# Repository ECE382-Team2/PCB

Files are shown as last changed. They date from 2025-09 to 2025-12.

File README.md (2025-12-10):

# OreoFT PCB

We used the Capacitance Comb library to automatically generate various configurations of capacitive comb structures for our capacitive force-torque (FT) sensor. Using the library in double-sided mode allowed us to create identical electrode traces for the top and bottom layers, ensuring symmetry and consistency. This automated generation process streamlined our sensor bring-up and improved design repeatability across different PCB configurations.

## PCB Configurations
There are multiple PCB configurations that vary by trace width, trace spacing, and the overall diameter of the electrode array (the circle formed by the four quadrants of electrodes).

### Electrode Array Diameter: 35 mm

| Option | Trace Width (mm) | Trace Spacing (mm) |
|:---:|:---:|:---:|
| 1 | 0.2 | 0.2 |
| 2 | 0.4 | 0.4 |
| 3 | 0.4 | 0.2 |

### Electrode Array Diameter: 52 mm

| Option | Trace Width (mm) | Trace Spacing (mm) |
|:---:|:---:|:---:|
| 1 | 0.7 | 0.2 |
| 2 | 1.0 | 0.2 |
| 3 | 0.7 | 0.1 |

These configurations allow us to test how trace geometry and sensor diameter affect the sensor's response and sensitivity. 
Different trace configurations can be generated using the Capacitance Comb library parameters accordingly.

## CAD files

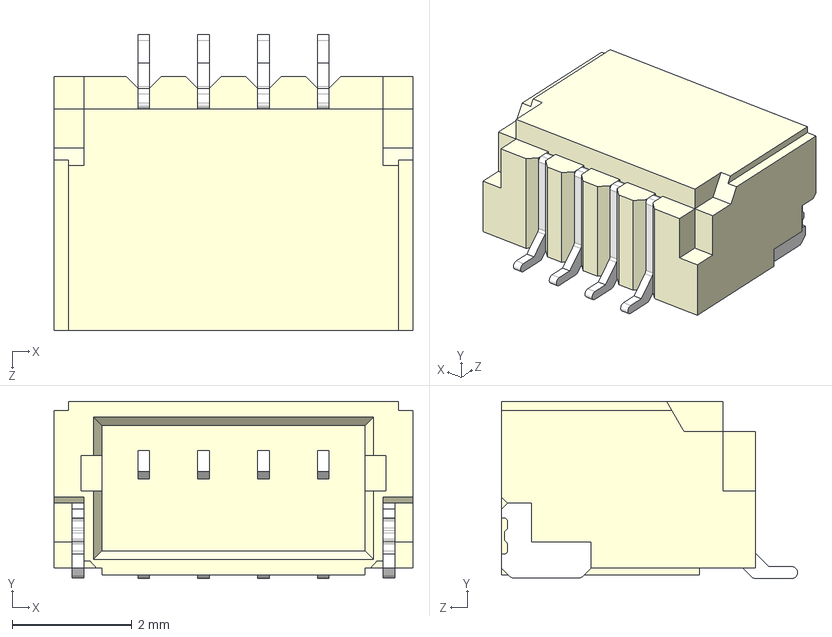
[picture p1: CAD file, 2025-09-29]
SM04B-SRSS-TB.STEP
6.00 x 2.96 x 4.95 mm

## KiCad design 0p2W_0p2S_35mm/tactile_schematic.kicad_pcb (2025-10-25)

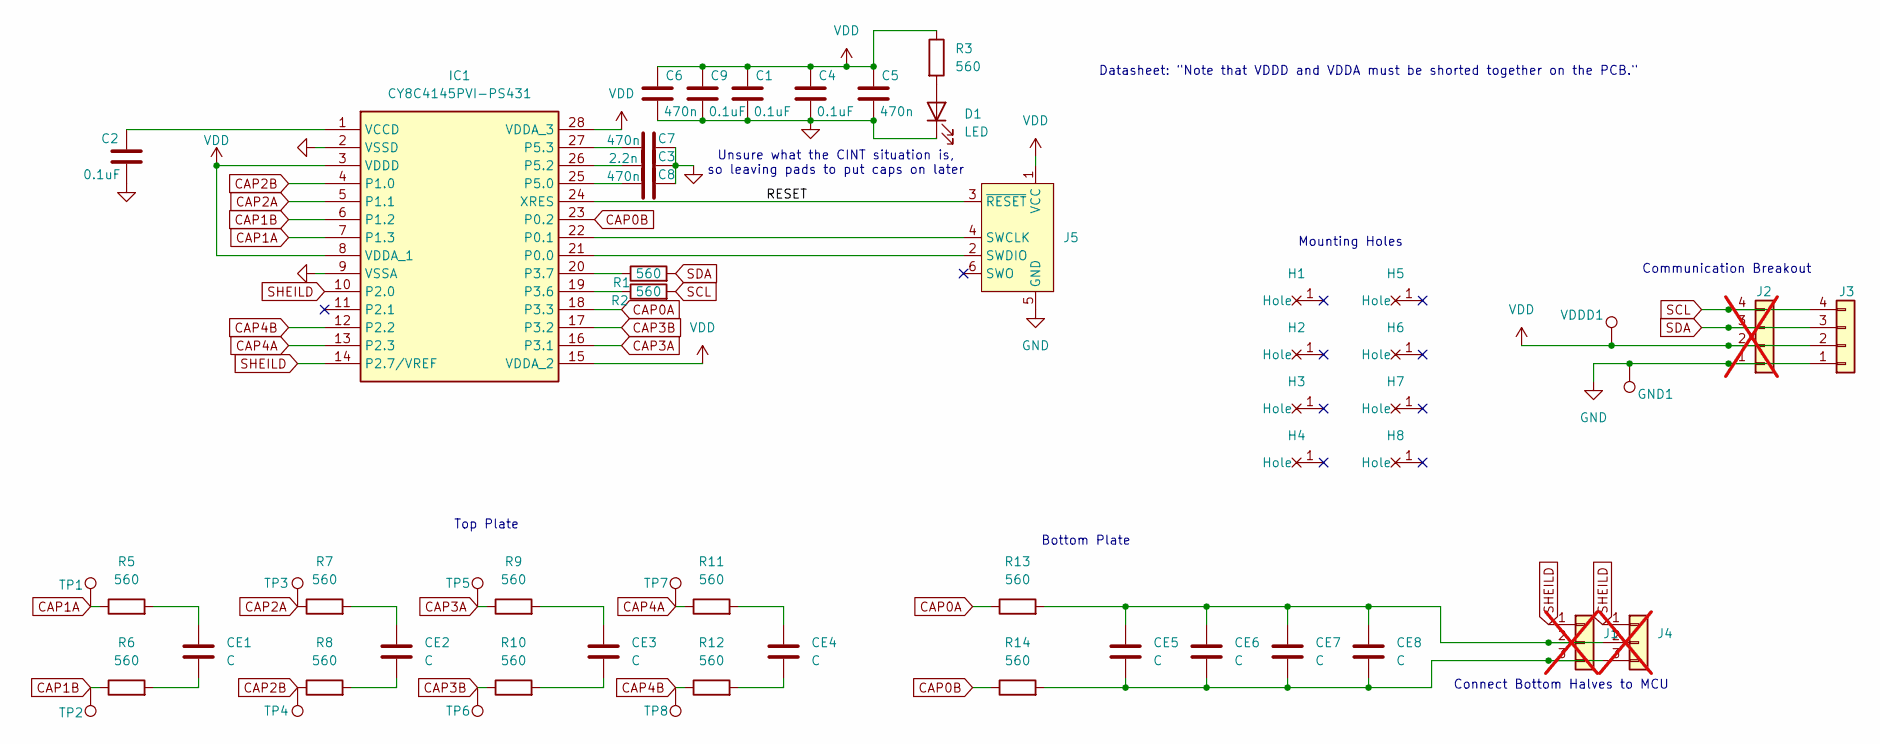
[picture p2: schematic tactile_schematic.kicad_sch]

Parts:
C1, C2, C4, C9: 0.1uF; C_0603_1608Metric_Pad1.08x0.95mm_HandSolder
C3: 2.2n; C_0603_1608Metric_Pad1.08x0.95mm_HandSolder
C5, C6, C7, C8: 470n; C_0603_1608Metric_Pad1.08x0.95mm_HandSolder
CE1, CE2, CE3, CE4: C; 02W_02S_COIL_BACK
CE5, CE6, CE7, CE8: C; 02W_02S__COIL_FRONT
D1: LED; LED_0603_1608Metric
GND1: TestPoint; TestPoint_THTPad_D1.0mm_Drill0.5mm
H1, H2, H3, H4, H5, H6, H7, H8: MountingHole_3.2mm_M3_Pad
IC1: CY8C4145PVI-PS431; SOP65P780X200-28N; Manufacturer_Part_Number CY8C4145PVI-PS431
J1, J4: Conn_01x03; PinHeader_1x03_P2.00mm_Vertical; not fitted
J2: Conn_01x04; PinHeader_1x04_P1.27mm_Vertical; not fitted
J3: Conn_01x04; JST_SH_SM04B-SRSS-TB_1x04-1MP_P1.00mm_Horizontal
J5: Conn_ARM_SWD_TagConnect_TC2030-NL; Tag-Connect_TC2030-IDC-NL_2x03_P1.27mm_Vertical
R1, R2, R3, R5, R6, R7, R8, R9, R10, R11, R12, R13, R14: 560; R_0603_1608Metric_Pad0.98x0.95mm_HandSolder
TP1, TP2, TP3, TP4, TP5, TP6, TP7, TP8: TestPoint; TestPoint_THTPad_D1.0mm_Drill0.5mm
VDDD1: TestPoint; TestPoint_THTPad_D1.0mm_Drill0.5mm

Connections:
/RESET: IC1.24 (XRES), J5.3 (~RESET)
CAP0A: IC1.18 (P3.3), R13.1
CAP0B: IC1.23 (P0.2), R14.1
CAP1A: IC1.7 (P1.3), R5.1, TP1.1
CAP1B: IC1.6 (P1.2), R6.1, TP2.1
CAP2A: IC1.5 (P1.1), R7.1, TP3.1
CAP2B: IC1.4 (P1.0), R8.1, TP4.1
CAP3A: IC1.16 (P3.1), R9.1, TP5.1
CAP3B: IC1.17 (P3.2), R10.1, TP6.1
CAP4A: IC1.13 (P2.3), R11.1, TP7.1
CAP4B: IC1.12 (P2.2), R12.1, TP8.1
GND: C1.2, C2.2, C3.2, C4.2, C5.2, C6.2, C7.2, C8.2, C9.2, D1.1 (K), GND1.1, IC1.2 (VSSD), IC1.9 (VSSA), J2.1, J3.1, J5.5 (GND)
unnamed: CE1.1, R5.2
unnamed: CE1.2, R6.2
unnamed: CE2.1, R7.2
unnamed: CE2.2, R8.2
unnamed: CE3.1, R9.2
unnamed: CE3.2, R10.2
unnamed: CE4.1, R11.2
unnamed: CE4.2, R12.2
unnamed: D1.2 (A), R3.2
unnamed: IC1.21 (P0.0), J5.2 (SWDIO)
unnamed: IC1.22 (P0.1), J5.4 (SWCLK)
unnamed: IC1.19 (P3.6), R2.1
unnamed: IC1.20 (P3.7), R1.1
unnamed: C8.1, IC1.25 (P5.0)
unnamed: C3.1, IC1.26 (P5.2)
unnamed: C7.1, IC1.27 (P5.3)
unnamed: C2.1, IC1.1 (VCCD)
unnamed: CE5.1, CE6.1, CE7.1, CE8.1, J1.2, J4.2, R13.2
unnamed: CE5.2, CE6.2, CE7.2, CE8.2, J1.3, J4.3, R14.2
SCL: J2.4, J3.4, R2.2
SDA: J2.3, J3.3, R1.2
SHEILD: IC1.10 (P2.0), IC1.14 (P2.7/VREF), J1.1, J4.1
VDD: C1.1, C4.1, C5.1, C6.1, C9.1, IC1.3 (VDDD), IC1.8 (VDDA_1), IC1.15 (VDDA_2), IC1.28 (VDDA_3), J2.2, J3.2, J5.1 (VCC), R3.1, VDDD1.1

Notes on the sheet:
Datasheet: "Note that VDDD and VDDA must be shorted together on the PCB."
Top Plate
Mounting Holes
Unsure what the CINT situation is, so leaving pads to put caps on later
Bottom Plate
Communication Breakout
Connect Bottom Halves to MCU

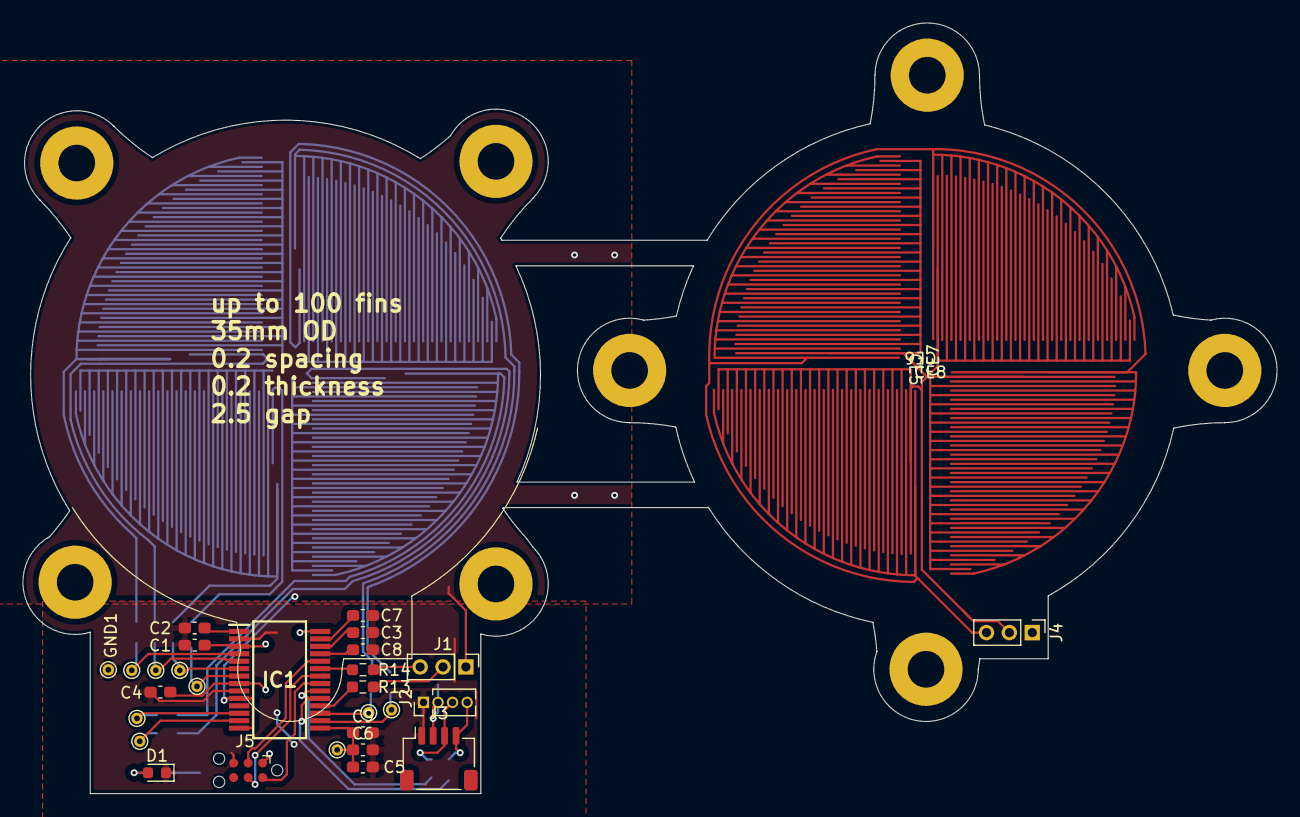
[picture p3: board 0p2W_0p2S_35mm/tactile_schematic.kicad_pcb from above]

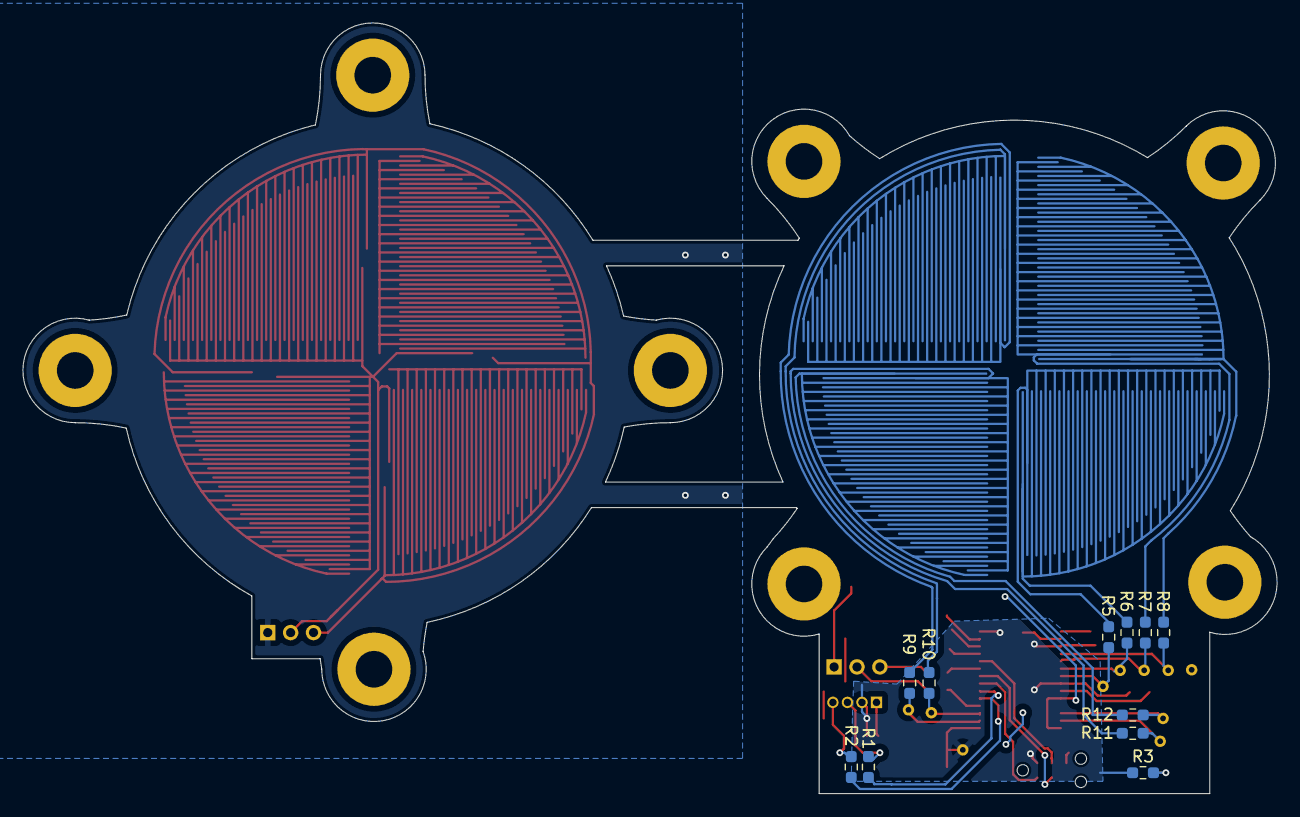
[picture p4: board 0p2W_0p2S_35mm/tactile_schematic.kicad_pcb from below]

Board: 2 copper layers, 109.6 x 67.4 mm, 55 parts (11 on the bottom side), 35 nets.

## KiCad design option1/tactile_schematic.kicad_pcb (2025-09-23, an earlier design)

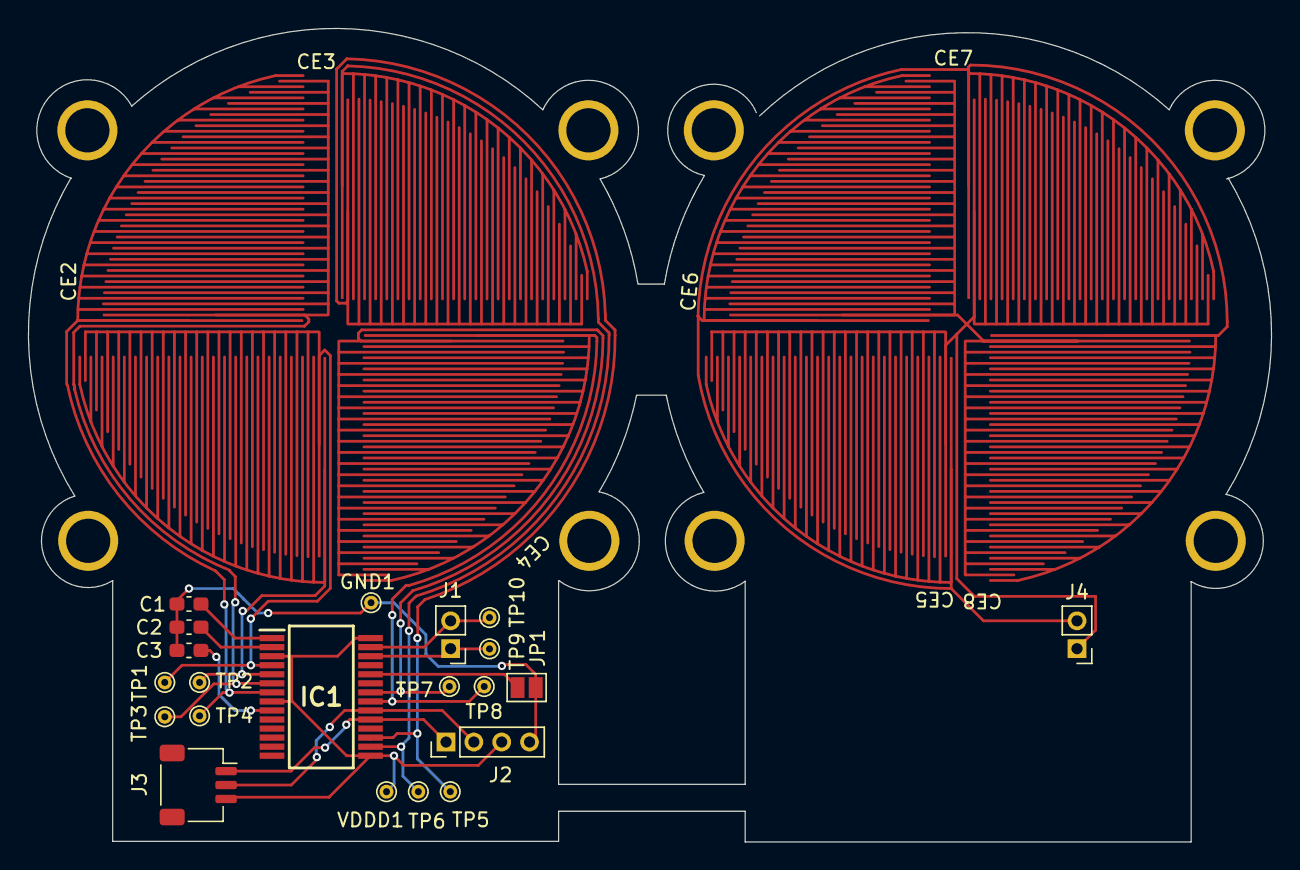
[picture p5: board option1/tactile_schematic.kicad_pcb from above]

Board: 2 copper layers, 89.3 x 58.4 mm, 37 parts (0 on the bottom side), 18 nets.

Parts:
C1, C2, C3: 0.1uF; C_0603_1608Metric_Pad1.08x0.95mm_HandSolder
CE1, CE2, CE3, CE4, CE5, CE6, CE7, CE8: C; COIL_GENERATOR
GND1: TestPoint; TestPoint_THTPad_D1.0mm_Drill0.5mm
H1, H2, H3, H4, H5, H6, H7, H8: MountingHole_4_40
IC1: CY8C4145PVI-PS431; SOP65P780X200-28N
J1, J4: Conn_01x02; PinHeader_1x02_P2.00mm_Vertical
J2: Conn_01x04; PinHeader_1x04_P2.00mm_Vertical
J3: Conn_01x04; JST_SH_SM03B-SRSS-TB_1x03-1MP_P1.00mm_Horizontal
JP1: SolderJumper_2_Open; SolderJumper-2_P1.3mm_Open_Pad1.0x1.5mm
TP1, TP2, TP3, TP4, TP5, TP6, TP7, TP8, TP9, TP10: TestPoint; TestPoint_THTPad_D1.0mm_Drill0.5mm
VDDD1: TestPoint; TestPoint_THTPad_D1.0mm_Drill0.5mm

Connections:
GND: C1.2, C2.2, C3.2, GND1.1, J2.4, JP1.2 (B)
unnamed: C1.1, IC1.1 (VCCD)
unnamed: C3.1, IC1.9 (VSSA)
unnamed: C2.1, IC1.2 (VSSD)
unnamed: IC1.24 (XRES), JP1.1 (A)
P0.0: CE4.2, IC1.21 (P0.0), TP8.1
P0.1: CE4.1, IC1.22 (P0.1), TP7.1
P1.0: CE1.1, IC1.4 (P1.0), TP1.1
P1.1: CE1.2, IC1.5 (P1.1), TP2.1
P1.2: CE2.1, IC1.6 (P1.2), TP3.1
P1.3: CE2.2, IC1.7 (P1.3), TP4.1
P3.1: CE3.2, IC1.16 (P3.1), TP6.1
P3.2: CE3.1, IC1.17 (P3.2), TP5.1
P3.6: IC1.19 (P3.6), J2.1, J3.1
P3.7: IC1.20 (P3.7), J2.2, J3.2
P5.2: CE5.1, CE6.1, CE7.1, CE8.1, IC1.26 (P5.2), J1.1, J4.1, TP9.1
P5.3: CE5.2, CE6.2, CE7.2, CE8.2, IC1.27 (P5.3), J1.2, J4.2, TP10.1
VDDA_1: IC1.3 (VDDD), IC1.8 (VDDA_1), IC1.15 (VDDA_2), IC1.28 (VDDA_3), J2.3, J3.3, VDDD1.1

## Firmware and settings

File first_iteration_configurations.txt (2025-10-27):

====================================
PCB TRACE CONFIGURATIONS
====================================

OPTION 1
------------------------------------
Outer diameter  : 36 mm
Trace width     : 0.4 mm
Trace spacing   : 0.2 mm
------------------------------------


OPTION 2
------------------------------------
Outer diameter  : 52 mm
Trace width     : 0.7 mm
Trace spacing   : 0.2 mm
------------------------------------


OPTION 3
------------------------------------
Outer diameter  : 52 mm
Trace width     : 1.0 mm
Trace spacing   : 0.2 mm
------------------------------------

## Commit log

2025-09-09 started coinft schematic, uploaded A7417AR model
2025-09-22 initial schematic and layout upload
    [tactile_schematic.kicad_pcb, tactile_schematic.kicad_sch]
2025-09-23 need to fix edge cuts not lining up
    [tactile_schematic.kicad_pcb, tactile_schematic.kicad_sch]
2025-09-24 PCB first draft
    [tactile_schematic.kicad_pcb, tactile_schematic.kicad_sch]
2025-09-24 redid layout, pushed circuits down a bit
    [tactile_schematic.kicad_pcb, tactile_schematic.kicad_sch, tactile_schematic.step]
2025-09-24 fixed silkscreen
    [tactile_schematic.kicad_pcb]
2025-09-25 schematic file
    [tactile_schematic.kicad_sch]
2025-09-29 many changes
    [tactile_schematic.kicad_pcb, tactile_schematic.kicad_sch]
2025-09-29 KiCAD mod files
2025-09-30 three pcb trace configurations
    [pcb_trace_configurations.txt, tactile_schematic.kicad_pcb, tactile_schematic.kicad_sch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]
2025-10-25 - remove RST pad - change all resistors to 560ohm - remove UART test points - relayout with cleaning - conosolidate down to 3 capacitor values (replace 1uf w/ paralel 2 470ufs) - add power LED - move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
    [tactile_schematic.kicad_pcb, tactile_schematic.kicad_sch]
2025-10-27 three new pbs initial upload
    [tactile_schematic.kicad_pcb, tactile_schematic.kicad_sch, tactile_schematic.step]
2025-10-27 first and second pcb iteration configurations
    [first_iteration_configurations.txt, second_iteration_configuration.txt]
2025-10-27 gitignore *.lck
    [pcb_trace_configurations.txt]
2025-10-28 update configs
    [first_iteration_config.txt, second_iteration_config.txt]
2025-10-28 0.7mm width, 0.1 spacing, 52mm diameter initial upload
    [tactile_schematic.kicad_pcb, tactile_schematic.kicad_sch, tactile_schematic.step]
2025-10-28 rm old configs
    [first_iteration_config.txt, second_iteration_config.txt]
2025-10-28 update pcb configs
    [first_iteration_configs.txt, second_iteration_configs.txt]
2025-10-29 make spacing fixes (first two boards)
    [tactile_schematic.kicad_pcb, tactile_schematic.kicad_sch, tactile_schematic.step]
2025-10-29 more spacing fixes
    [tactile_schematic.kicad_pcb, tactile_schematic.kicad_sch]
2025-10-29 last sizing + pin2.7 changes
    [tactile_schematic.kicad_pcb]
2025-10-29 trace thickness & rebuild planes
    [tactile_schematic.kicad_pcb]
2025-10-29 move prog connector up, make bottom of gnd plane connected propelrly
    [tactile_schematic.kicad_pcb]
2025-10-29 straightened gnd plane
    [tactile_schematic.kicad_pcb]
2025-10-29 fix gnd plane
    [tactile_schematic.kicad_pcb]
2025-10-29 wills trace changes
    [tactile_schematic.kicad_pcb]
2025-10-29 remove redundant gnd trace by scl on larger pcbs
    [tactile_schematic.kicad_pcb]
2025-10-29 fixed drc error
    [tactile_schematic.kicad_pcb]
2025-10-29 Last trace changes by will
    [tactile_schematic.kicad_pcb]
2025-12-10 rm unused files
    [first_iteration_configs.txt, second_iteration_configs.txt]
